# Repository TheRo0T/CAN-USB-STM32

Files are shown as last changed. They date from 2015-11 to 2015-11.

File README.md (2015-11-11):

# CAN-USB-STM32
CAN-USB adapter based on [STM32F105](http://www.st.com/web/en/catalog/mmc/SC1169/SS1031/LN1564) microprocessor

Fault tolerant [CAN](https://en.wikipedia.org/wiki/CAN) using [TJA1055T](http://www.nxp.com/products/interface_and_connectivity/can_lin_flexray_transceivers/can_transceivers/TJA1055T.html)

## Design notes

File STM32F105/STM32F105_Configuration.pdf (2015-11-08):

## STM32F105 Project Configuration Report

# 1. Description

## 1.1. Project

Project Name | STM32F105
Board Name | STM32F105
Generated with: | STM32CubeMX 4.11.0
Date | 11/07/2015

## 1.2. MCU

MCU Series | STM32F1
MCU Line | STM32F105/107
MCU name | STM32F105RBTx
MCU Package | LQFP64
MCU Pin number | 64

# 2. Pinout Configuration

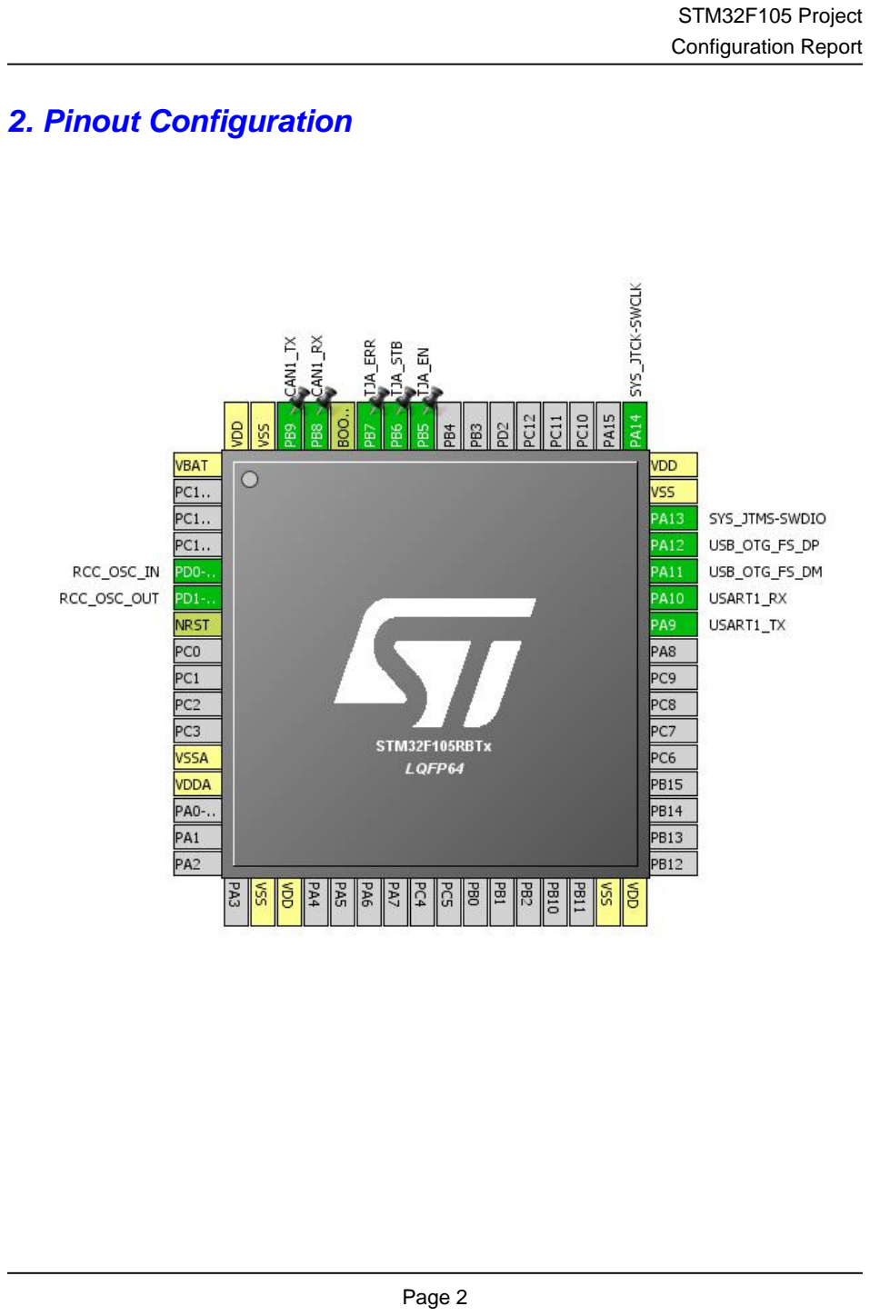
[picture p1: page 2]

# 3. Pins Configuration

Pin Number LQFP64 | Pin Name (function after reset) | Pin Type | Alternate Function(s) | Label
1 | VBAT | Power
5 | PD0-OSC_IN | I/O | RCC_OSC_IN
6 | PD1-OSC_OUT | I/O | RCC_OSC_OUT
7 | NRST | Reset
12 | VSSA | Power
13 | VDDA | Power
18 | VSS | Power
19 | VDD | Power
31 | VSS | Power
32 | VDD | Power
42 | PA9 | I/O | USART1_TX
43 | PA10 | I/O | USART1_RX
44 | PA11 | I/O | USB_OTG_FS_DM
45 | PA12 | I/O | USB_OTG_FS_DP
46 | PA13 | I/O | SYS_JTMS-SWDIO
47 | VSS | Power
48 | VDD | Power
49 | PA14 | I/O | SYS_JTCK-SWCLK
57 | PB5 * | I/O | GPIO_Output | TJA_EN
58 | PB6 * | I/O | GPIO_Output | TJA_STB
59 | PB7 * | I/O | GPIO_Input | TJA_ERR
60 | BOOT0 | Boot
61 | PB8 | I/O | CAN1_RX
62 | PB9 | I/O | CAN1_TX
63 | VSS | Power
64 | VDD | Power

## * The pin is affected with an I/O function

# 4. Clock Tree Configuration

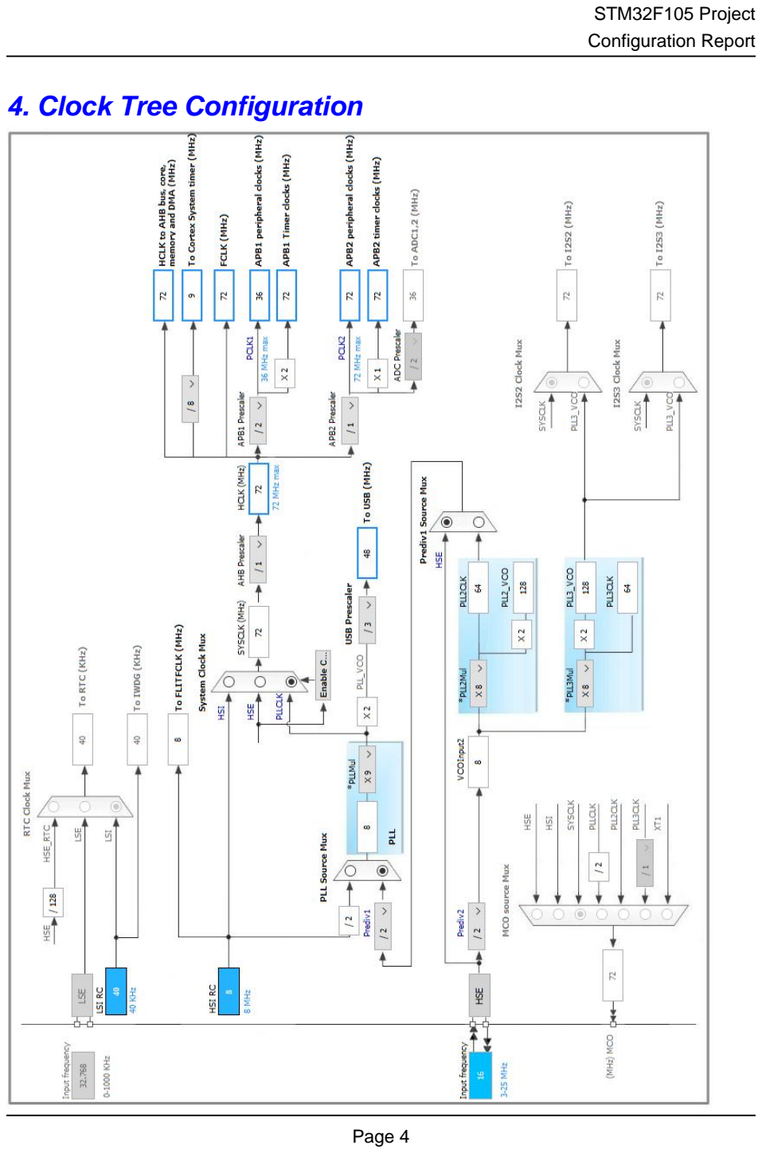
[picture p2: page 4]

# 5. IPs and Middleware Configuration

# 5.1. CAN1

## mode: Mode

## 5.1.1. Parameter Settings:

### Bit Timings Parameters:

Prescaler (for Time Quantum) | 6 *
Time Quantum | 166.66666666666669 *
Time Quanta in Bit Segment 1 | 6 Times *
Time Quanta in Bit Segment 2 | 5 Times *
Time for one Bit | 2000 *
ReSynchronization Jump Width | 1 Time

### Basic Parameters:

Time Triggered Communication Mode | Disable
Automatic Bus-Off Management | Disable
Automatic Wake-Up Mode | Disable
No-Automatic Retransmission | Disable
Receive Fifo Locked Mode | Disable
Transmit Fifo Priority | Disable

### Advanced Parameters:

Operating Mode | Loopback combined with Silent *

# 5.2. RCC

## High Speed Clock (HSE): Crystal/Ceramic Resonator

## 5.2.1. Parameter Settings:

### System Parameters:

VDD voltage (V) | 3.3
Instruction Cache | Enabled
Prefetch Buffer | Enabled
Data Cache | Enabled
Flash Latency(WS) | 2 WS (3 CPU cycle)

### RCC Parameters:

HSI Calibration Value | 16

# 5.3. SYS

## Debug: Serial-Wire

# 5.4. USART1

## Mode: Asynchronous

## 5.4.1. Parameter Settings:

### Basic Parameters:

Baud Rate | 115200
Word Length | 8 Bits (including Parity)
Parity | None
Stop Bits | 1

### Advanced Parameters:

Data Direction | Receive and Transmit
Over Sampling | 16 Samples

# 5.5. USB_OTG_FS

## Mode: Device_Only

## 5.5.1. Parameter Settings:

Speed | Device Full Speed 12MBit/s
Endpoint 0 Max Packet size | 64 Bytes
Low power | Disabled
VBUS sensing | Disabled

# 5.6. FREERTOS

## mode: Enabled

## 5.6.1. Config parameters:

### Versions:

CMSIS-RTOS version | 1.02
FreeRTOS version | 8.2.1

### Kernel settings:

USE_PREEMPTION | Enabled
CPU_CLOCK_HZ | SystemCoreClock
TICK_RATE_HZ | 1000
MAX_PRIORITIES | 7
MINIMAL_STACK_SIZE | 128
MAX_TASK_NAME_LEN | 16
USE_16_BIT_TICKS | Disabled
IDLE_SHOULD_YIELD | Enabled
USE_MUTEXES | Enabled
USE_RECURSIVE_MUTEXES | Enabled
USE_COUNTING_SEMAPHORES | Enabled
QUEUE_REGISTRY_SIZE | 8
USE_APPLICATION_TASK_TAG | Disabled
TOTAL_HEAP_SIZE | 4096
Memory Management scheme | heap_4
USE_ALTERNATIVE_API | Disabled
ENABLE_BACKWARD_COMPATIBILITY | Enabled
USE_PORT_OPTIMISED_TASK_SELECTION | Disabled
USE_TICKLESS_IDLE | Disabled

### Hook function related definitions:

USE_IDLE_HOOK | Disabled
USE_TICK_HOOK | Disabled
USE_MALLOC_FAILED_HOOK | Disabled
CHECK_FOR_STACK_OVERFLOW | Disabled

### Run time and task stats gathering related definitions:

USE_TRACE_FACILITY | Enabled
GENERATE_RUN_TIME_STATS | Disabled

### Co-routine related definitions:

USE_CO_ROUTINES | Disabled
MAX_CO_ROUTINE_PRIORITIES | 2

### Software timer definitions:

USE_TIMERS | Disabled
TIMER_TASK_PRIORITY | 2
TIMER_QUEUE_LENGTH | 10

### Interrupt nesting behaviour configuration:

LIBRARY_LOWEST_INTERRUPT_PRIORITY | 15
LIBRARY_MAX_SYSCALL_INTERRUPT_PRIORITY | 5

## 5.6.2. Include parameters:

### Include definitions:

vTaskPrioritySet | Enabled
uxTaskPriorityGet | Enabled
vTaskDelete | Enabled
vTaskCleanUpResources | Disabled
vTaskSuspend | Enabled
vTaskDelayUntil | Disabled
vTaskDelay | Enabled
xTaskGetSchedulerState | Enabled
xTaskResumeFromISR | Enabled
xQueueGetMutexHolder | Disabled
xSemaphoreGetMutexHolder | Disabled
pcTaskGetTaskName | Disabled
uxTaskGetStackHighWaterMark | Disabled
xTaskGetCurrentTaskHandle | Disabled
eTaskGetState | Disabled
xEventGroupSetBitFromISR | Disabled
xTimerPendFunctionCall | Disabled

# 5.7. USB_DEVICE

## Class For FS IP: Communication Device Class (Virtual Port Com)

## 5.7.1. Parameter Settings:

### Basic Parameters:

USBD_MAX_NUM_INTERFACES (Maximum number of supported interfaces) | 1
USBD_MAX_NUM_CONFIGURATION (Maximum number of supported configuration) | 1
USBD_MAX_STR_DESC_SIZ (Maximum size for the string descriptors) | 512
USBD_SUPPORT_USER_STRING (Enable user string descriptor) | Disabled
USBD_SELF_POWERED (Enabled self power) | Enabled
USBD_DEBUG_LEVEL (USBD Debug Level) | 0: No debug message

### Class Parameters:

USBD_CDC_INTERVAL (Number of micro-frames interval) | 1000

## 5.7.2. Device Descriptor:

### Device Descriptor:

VID (Vendor IDentifier) | 1155
LANGID_STRING (Language Identifier) | English(United States)
MANUFACTURER_STRING (Manufacturer Identifier) | STMicroelectronics

### Device Descriptor FS:

PID (Product IDentifier) | 22336
PRODUCT_STRING (Product Identifier) | STM32 Virtual ComPort
SERIALNUMBER_STRING (Serial number) | 00000000001A
CONFIGURATION_STRING (Configuration Identifier) | CDC Config
INTERFACE_STRING (Interface Identifier) | CDC Interface

### * User modified value

# 6. System Configuration

# 6.1. GPIO configuration

IP | Pin | Signal | GPIO mode | GPIO pull/up pull down | Max Speed | User Label
CAN1 | PB8 | CAN1_RX | Input mode | No pull-up and no pull-down | n/a
| PB9 | CAN1_TX | Alternate Function Push Pull | n/a | High *
RCC | PD0-OSC_IN | RCC_OSC_IN | n/a | n/a | n/a
| PD1-OSC_OUT | RCC_OSC_OUT | n/a | n/a | n/a
SYS | PA13 | SYS_JTMS-SWDIO | n/a | n/a | n/a
| PA14 | SYS_JTCK-SWCLK | n/a | n/a | n/a
USART1 | PA9 | USART1_TX | Alternate Function Push Pull | n/a | High *
| PA10 | USART1_RX | Input mode | No pull-up and no pull-down | n/a
USB_OTG_ FS | PA11 | USB_OTG_FS_ DM | n/a | n/a | n/a
| PA12 | USB_OTG_FS_ DP | n/a | n/a | n/a
GPIO | PB5 | GPIO_Output | Output Push Pull | n/a | Low | TJA_EN
| PB6 | GPIO_Output | Output Push Pull | n/a | Low | TJA_STB
| PB7 | GPIO_Input | Input mode | No pull-up and no pull-down | n/a | TJA_ERR

# 6.2. DMA configuration

DMA request | Stream | Direction | Priority
USART1_TX | DMA1_Channel4 | Memory To Peripheral | Low
USART1_RX | DMA1_Channel5 | Peripheral To Memory | Low

## USART1_TX: DMA1_Channel4 DMA request Settings:

Mode: | Normal
Peripheral Increment: | Disable
Memory Increment: | Enable *
Peripheral Data Width: | Byte
Memory Data Width: | Byte

## USART1_RX: DMA1_Channel5 DMA request Settings:

Mode: | Circular *
Peripheral Increment: | Disable
Memory Increment: | Enable *
Peripheral Data Width: | Byte
Memory Data Width: | Byte

# 6.3. NVIC configuration

Interrupt Table | Enable | Preenmption Priority | SubPriority
System tick timer | true | 0 | 0
DMA1 channel4 global interrupt | true | 5 | 0
DMA1 channel5 global interrupt | true | 5 | 0
CAN1 TX interrupt | true | 5 | 0
CAN1 RX0 interrupt | true | 5 | 0
CAN1 RX1 interrupt | true | 5 | 0
CAN1 SCE interrupt | true | 5 | 0
USART1 global interrupt | true | 5 | 0
USB OTG FS global interrupt | true | 5 | 0
Non maskable interrupt | unused
Memory management fault | unused
Prefetch fault, memory access fault | unused
Undefined instruction or illegal state | unused
Debug monitor | unused
PVD interrupt through EXTI line 16 | unused
Flash global interrupt | unused
RCC global interrupt | unused

### * User modified value

# 7. Power Plugin report

## 7.1. Microcontroller Selection

Series | STM32F1
Line | STM32F105/107
MCU | STM32F105RBTx
Datasheet | 15274_Rev9

## 7.2. Parameter Selection

Temperature | 25
Vdd | 3.3

# 8. Software Project

## 8.1. Project Settings

Name | Value
Project Name | STM32F105
Project Folder | C:\Users\Dmitry\workspace\STM32F105\STM32F105
Toolchain / IDE | SW4STM32
Firmware Package Name and Version | STM32Cube FW_F1 V1.2.0

## 8.2. Code Generation Settings

Name | Value
STM32Cube Firmware Library Package | Copy all used libraries into the project folder
Generate peripheral initialization as a pair of '.c/.h' files | No
Backup previously generated files when re-generating | No
Delete previously generated files when not re-generated | Yes
Set all free pins as analog (to optimize the power consumption) | No

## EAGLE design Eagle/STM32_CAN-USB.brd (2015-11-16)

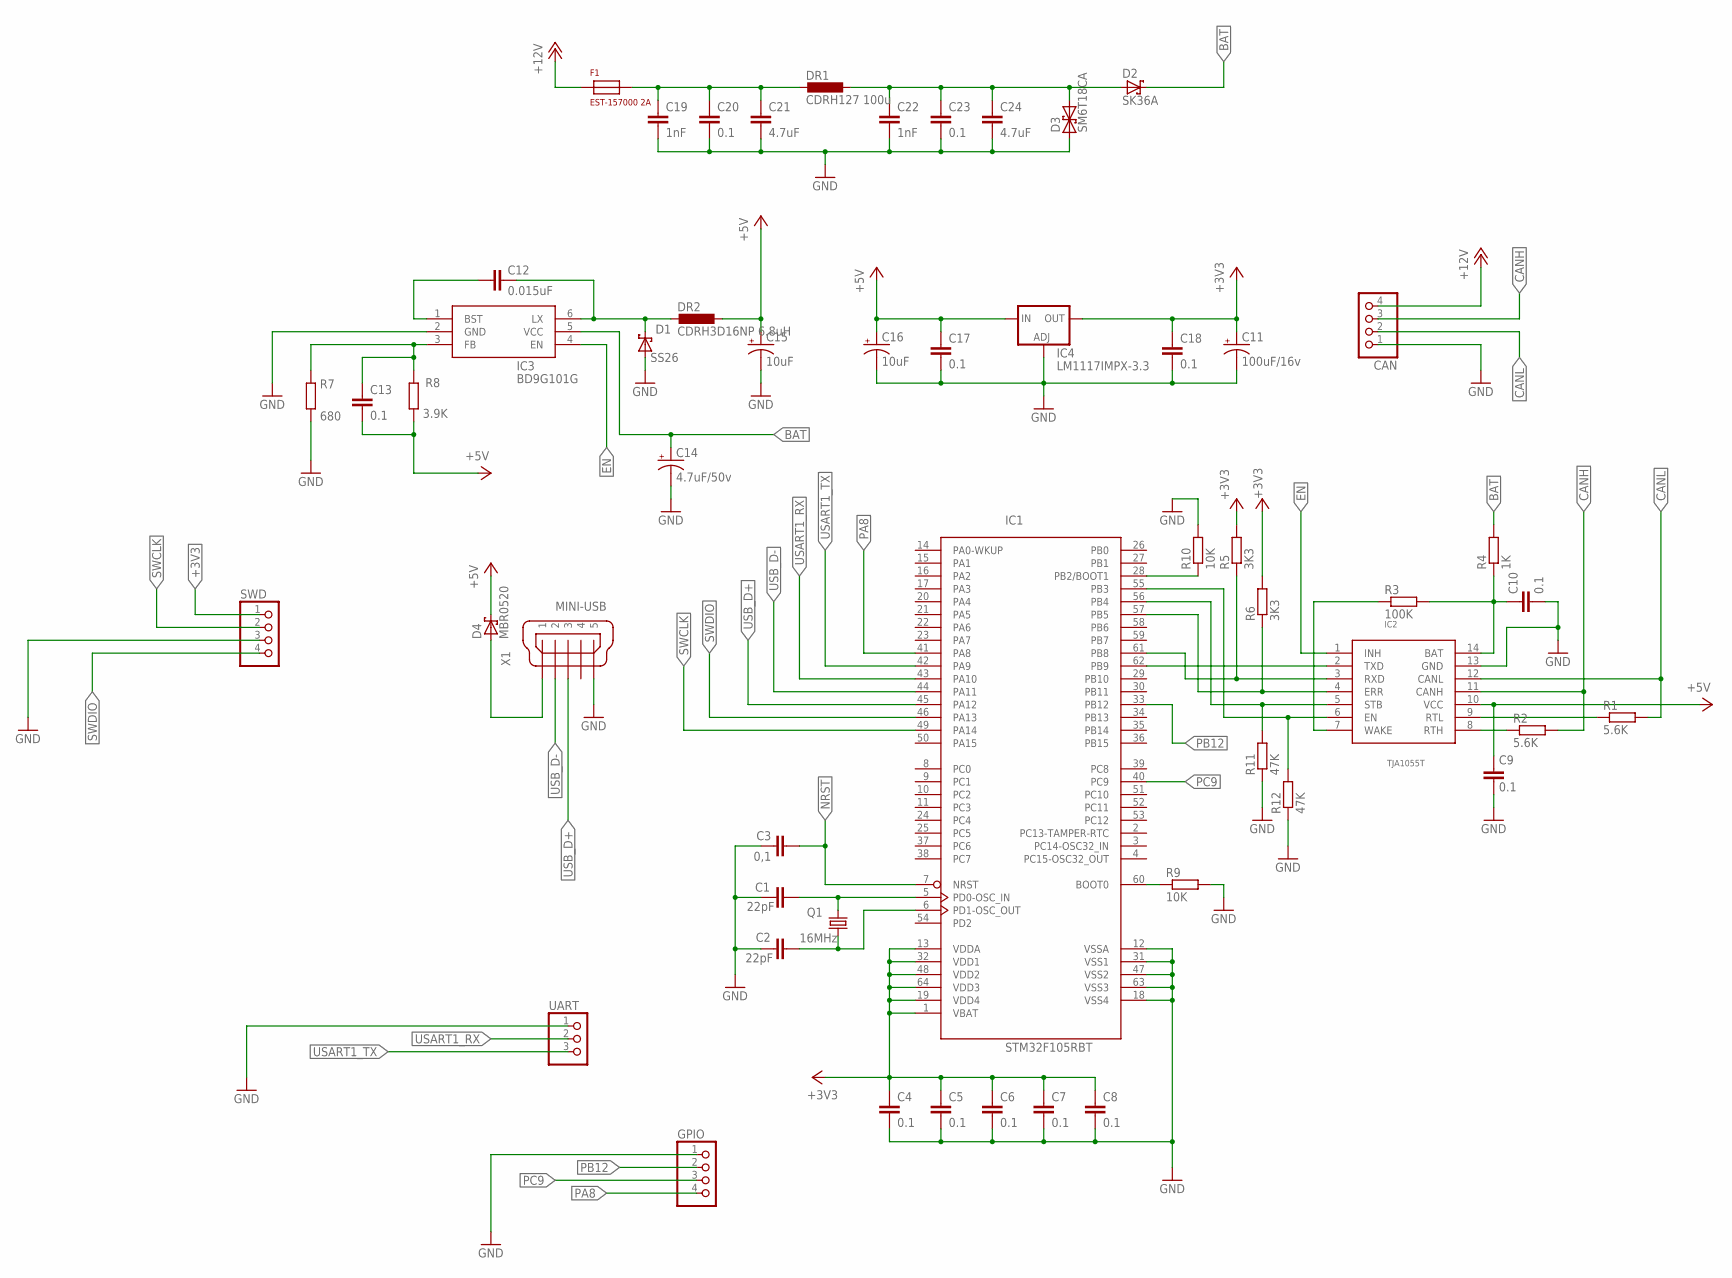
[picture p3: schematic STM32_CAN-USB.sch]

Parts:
C1, C2: 22pF; C0805
C3: 0,1; C0805
C4, C5, C6, C7, C8, C9, C10, C13, C17, C18, C20, C23: 0.1; C0805
C11: 100uF/16v; 153CLV-0605
C12: 0.015uF; C0805
C14: 4.7uF/50v; 153CLV-0605
C15, C16: 10uF; 153CLV-0605
C19, C22: 1nF; C0805
C21, C24: 4.7uF; C0805
CAN: PINHD-1X4; 1X04
D1: SS26; SMB
D2: SK36A; DO-214AC
D3: SM6T18CA; DO214AA
D4: MBR0520; SOD123
DR1: CDRH127 100u; MS85
DR2: CDRH3D16NP 6.8uH; CDRH3D16NP
F1: EST-157000 2A; FUSE
GPIO: PINHD-1X4; 1X04
IC1: STM32F105RBT; LQFP64
IC2: TJA1055T; SO-14W
IC3: BD9G101G; SSOP6
IC4: LM1117IMPX-3.3; SOT223
Q1: 16MHz; HC49UP
R1, R2: 5.6K; R0805
R3: 100K; R0805
R4: 1K; R0805
R5, R6: 3K3; R0805
R7: 680; R0805
R8: 3.9K; R0805
R9, R10: 10K; R0805
R11, R12: 47K; R0805
SWD: PINHD-1X4; 1X04
UART: PINHD-1X3; 1X03
X1: MINI-USB; UX60-MB-5ST

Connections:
+3V3: C4.1, C5.1, C6.1, C7.1, C8.1, C11.+, C18.1, IC1.1 (VBAT), IC1.13 (VDDA), IC1.19 (VDD4), IC1.32 (VDD1), IC1.48 (VDD2), IC1.64 (VDD3), IC4.2 (OUT), IC4.4 (OUT), R5.2, R6.2, SWD.1
+5V: C9.1, C13.2, C15.+, C16.+, C17.1, D4.C, DR2.P$2 (2), IC2.10 (VCC), IC4.3 (IN), R8.1
+12V: CAN.4, F1.P$1 (1)
BAT: C14.+, D2.C, IC3.5 (VCC), R4.2
CANH: CAN.3, IC2.11 (CANH), R2.2
CANL: CAN.2, IC2.12 (CANL), R1.2
EN: IC2.1 (INH), IC3.4 (EN)
GND: C1.2, C2.2, C3.1, C4.2, C5.2, C6.2, C7.2, C8.2, C9.2, C10.2, C11.-, C14.-, C15.-, C16.-, C17.2, C18.2, C19.2, C20.2, C21.2, C22.2, C23.2, C24.2, CAN.1, D1.A, D3.A (1), GPIO.1, IC1.12 (VSSA), IC1.18 (VSS4), IC1.31 (VSS1), IC1.47 (VSS2), IC1.63 (VSS3), IC2.13 (GND), IC3.2 (GND), IC4.1 (ADJ), R7.1, R9.2, R10.2, R11.1, R12.1, SWD.3, UART.1, X1.5, X1.M1 (5), X1.M2 (5)
unnamed: C1.1, IC1.5 (PD0-OSC_IN), Q1.2
unnamed: C2.1, IC1.6 (PD1-OSC_OUT), Q1.1
unnamed: IC1.60 (BOOT0), R9.1
unnamed: IC1.61 (PB8), IC2.3 (RXD), R5.1
unnamed: IC1.62 (PB9), IC2.2 (TXD)
unnamed: IC1.56 (PB4), IC2.5 (STB), R11.2
unnamed: IC2.8 (RTH), R2.1
unnamed: IC2.9 (RTL), R1.1
unnamed: C12.1, IC3.1 (BST)
unnamed: IC2.7 (WAKE), R3.1
unnamed: C10.1, IC2.14 (BAT), R3.2, R4.1
unnamed: C12.2, D1.C, DR2.P$1 (1), IC3.6 (LX)
unnamed: C13.1, IC3.3 (FB), R7.2, R8.2
unnamed: IC1.55 (PB3), IC2.6 (EN), R12.2
unnamed: IC1.57 (PB5), IC2.4 (ERR), R6.1
unnamed: IC1.28 (PB2/BOOT1), R10.1
unnamed: C22.1, C23.1, C24.1, D2.A, D3.C (2), DR1.P$2 (2)
unnamed: C19.1, C20.1, C21.1, DR1.P$1 (1), F1.P$2 (2)
unnamed: D4.A, X1.1
NRST: C3.2, IC1.7 (NRST)
PA8: GPIO.4, IC1.41 (PA8)
PB12: GPIO.2, IC1.33 (PB12)
PC9: GPIO.3, IC1.40 (PC9)
SWCLK: IC1.49 (PA14), SWD.2
SWDIO: IC1.46 (PA13), SWD.4
USART1_RX: IC1.43 (PA10), UART.2
USART1_TX: IC1.42 (PA9), UART.3
USB_D+: IC1.45 (PA12), X1.3
USB_D-: IC1.44 (PA11), X1.2

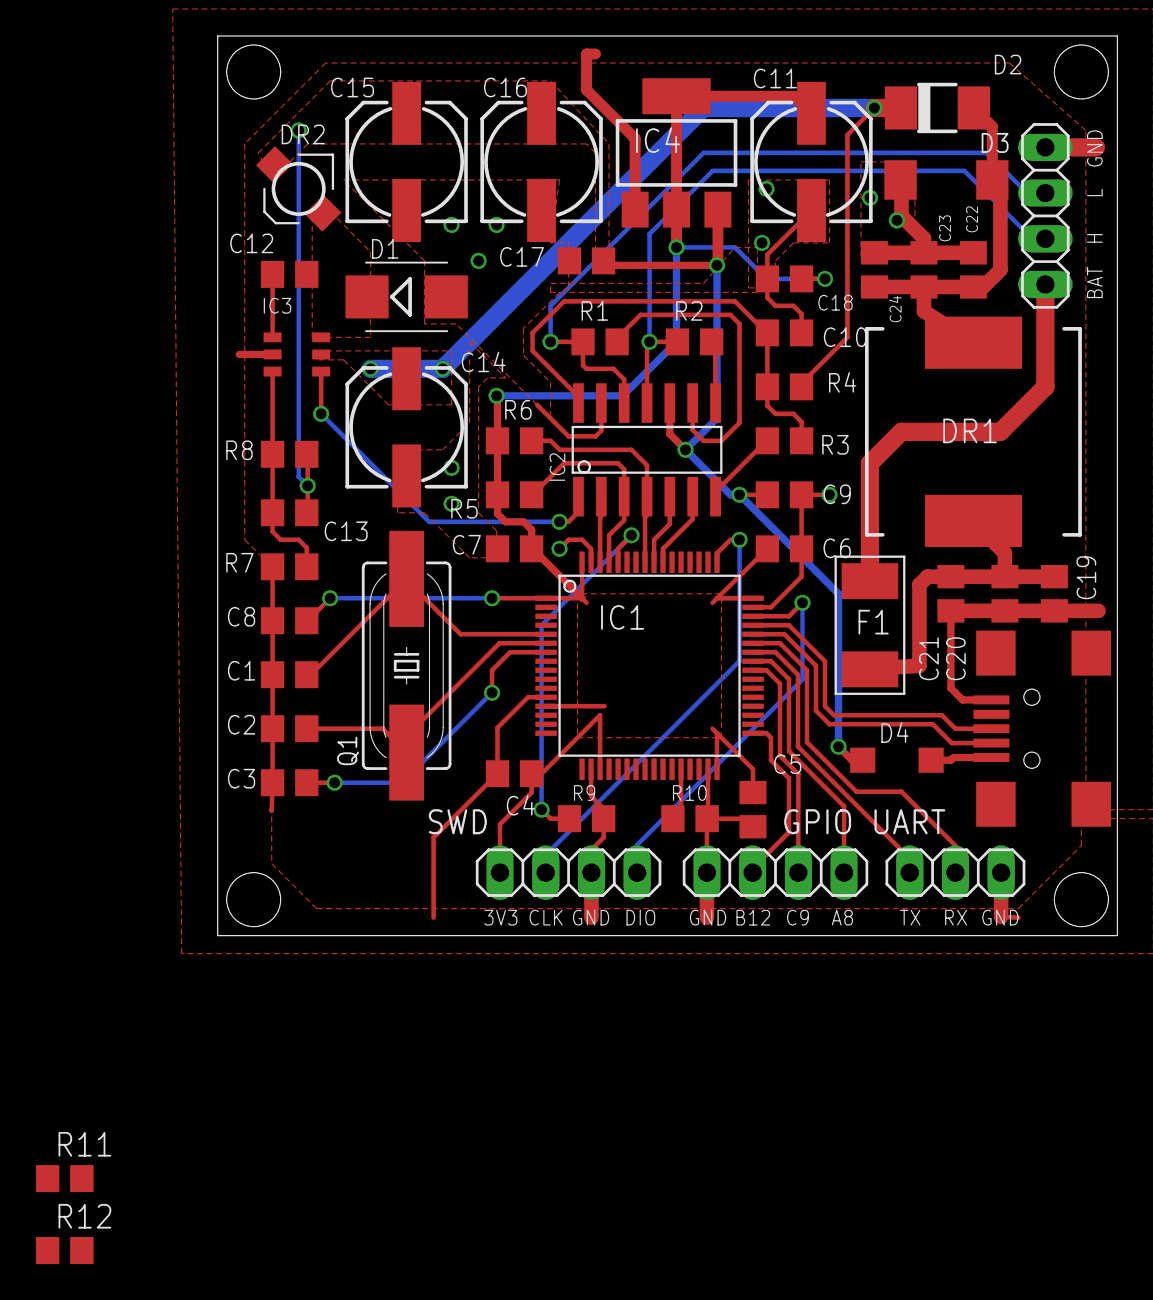
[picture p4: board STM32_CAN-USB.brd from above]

Board: 2 copper layers, 50.0 x 50.0 mm, 53 parts (0 on the bottom side), 37 nets.

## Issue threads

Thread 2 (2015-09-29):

Отверстия по углам слишком близко

autowp, 2015-09-29:
Отодвинуть от отверстий pin-header'ы, мешающие винтам

autowp, 2015-11-12:
Fixed https://github.com/TheRo0T/CAN-USB-STM32/commit/9308639844096602d4c6fb7fe465f3dd1f850d11

Closed 2015-11-12.

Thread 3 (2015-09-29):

Маркировка контактов

autowp, 2015-09-29:
Нанести слой с названиями контактов
- [x] SWD
- [x] UART
- [x] CAN
- [x] GPIO

autowp, 2015-11-05:
https://github.com/TheRo0T/CAN-USB-STM32/commit/35073f4e0025a2ff9baa2b1c0c24b0d2092b634e

autowp, 2015-11-11:
CAN - https://github.com/TheRo0T/CAN-USB-STM32/commit/147e032a0dbb3c5a9067781c5d7b40ddfc98dc47

autowp, 2015-11-12:
GPIO UART https://github.com/TheRo0T/CAN-USB-STM32/commit/9308639844096602d4c6fb7fe465f3dd1f850d11

Closed 2015-11-12.

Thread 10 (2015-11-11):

HAL CAN lock issue

autowp, 2015-11-11:
Решить проблему с падением CAN в Busy
[ST forum](https://my.st.com/public/STe2ecommunities/mcu/Lists/STM32Java/Flat.aspx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)

autowp, 2015-11-20:
Attempt to fix https://github.com/TheRo0T/CAN-USB-STM32/commit/cdca315223ea597243ea4956ae588b31252e0dda

Closed 2015-11-20.

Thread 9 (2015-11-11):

PWR LED

autowp, 2015-11-11:
Добавить индикацию наличия +5V (после DC-DC)
С учётом цели на корпус: не-smd.
Как вариант: 2-pin сокет для подключения светодиода на проводке, для отвязки от расположения на плате.

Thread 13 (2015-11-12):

RST button

autowp, 2015-11-12:
Добавить кнопку сброса

autowp, 2015-11-12:
Предлагаю объединить в 4-pin female (2x2) header кнопку сброса и светодиод PWR LED https://github.com/TheRo0T/CAN-USB-STM32/issues/9

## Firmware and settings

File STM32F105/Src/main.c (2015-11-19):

/**
  ******************************************************************************
  * File Name          : main.c
  * Description        : Main program body
  ******************************************************************************
  *
  * COPYRIGHT(c) 2015 STMicroelectronics
  *
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
  ******************************************************************************
  */
/* Includes ------------------------------------------------------------------*/
#include "stm32f1xx_hal.h"
#include "cmsis_os.h"
#include "usb_device.h"

/* USER CODE BEGIN Includes */
#include <string.h>
#include <stdlib.h>
#include "canhacker.h"
#include "tja1055.h"
/* USER CODE END Includes */

CAN_HandleTypeDef hcan1;

TIM_HandleTypeDef htim6;

UART_HandleTypeDef huart1;
DMA_HandleTypeDef hdma_usart1_tx;
DMA_HandleTypeDef hdma_usart1_rx;

osThreadId defaultTaskHandle;
osThreadId uartRxDmaTaskHandle;
osMessageQId uartTxQueueHandle;
osMessageQId canRxQueueHandle;
osMessageQId canTxQueueHandle;

/* USER CODE BEGIN PV */
#define UART_RX_LINE_BUFFER 80
int timer = 0;
uint8_t uartLine[UART_RX_LINE_BUFFER];
int uartLineIndex = 0;
#define UART_RX_BUFFER 256

CAN_HandleTypeDef hcan1;
static CanTxMsgTypeDef        can1TxMessage;
static CanRxMsgTypeDef        can1RxMessage;

TJA1055_HandleTypeDef tja1055;
CanHacker_HandleTypeDef hcanhacker;

typedef struct
{
    uint8_t buffer[UART_RX_BUFFER];
    uint8_t readed;
    uint8_t filled;
    int offset;
} UART_DMA_RX_Buffer;

#define UART_RX_BUFFERS_COUNT 2

UART_DMA_RX_Buffer uartRxBuffer[UART_RX_BUFFERS_COUNT]= {
    { .readed = 1, .filled = 0, .offset = 0 },
    { .readed = 1, .filled = 0, .offset = 0 }
};
int currentUartRxBuffer = 0;
int currentUartRxBufferToRead = 0;

/* USER CODE END PV */

void SystemClock_Config(void);
static void MX_GPIO_Init(void);
static void MX_DMA_Init(void);
static void MX_CAN1_Init(void);
static void MX_TIM6_Init(void);
static void MX_USART1_UART_Init(void);
void StartDefaultTask(void const * argument);
void StartUartRxDmaTask(void const * argument);

/* USER CODE BEGIN PFP */
void throwError(char *msg);

void txUart();
void txCan();
void rxCan();
void transmitErrorMessage(char *message);
/* USER CODE END PFP */

int main(void)
{

  /* MCU Configuration----------------------------------------------------------*/

  /* Reset of all peripherals, Initializes the Flash interface and the Systick. */
  HAL_Init();

  /* Configure the system clock */
  SystemClock_Config();

  /* Initialize all configured peripherals */
  MX_GPIO_Init();
  MX_DMA_Init();
  MX_CAN1_Init();
  MX_TIM6_Init();
  MX_USART1_UART_Init();

  /* USER CODE BEGIN 2 */

    tja1055.enPort = GPIOB;
    tja1055.enPin = TJA_EN_Pin;
    tja1055.errPort = GPIOB;
    tja1055.errPin = TJA_ERR_Pin;
    tja1055.stbPort = GPIOB;
    tja1055.stbPin = TJA_STB_Pin;
    TJA1055_Init(&tja1055);

    CanHacker_Init(&hcanhacker);

    hcan1.pTxMsg = &can1TxMessage;
    hcan1.pRxMsg = &can1RxMessage;


    CAN_FilterConfTypeDef canFilterConfig;
    canFilterConfig.FilterNumber = 0;
    canFilterConfig.FilterMode = CAN_FILTERMODE_IDMASK;
    canFilterConfig.FilterScale = CAN_FILTERSCALE_32BIT;
    canFilterConfig.FilterIdHigh = 0x0000;
    canFilterConfig.FilterIdLow = 0x0000;
    canFilterConfig.FilterMaskIdHigh = 0x0000 << 5;
    canFilterConfig.FilterMaskIdLow = 0x0000;
    canFilterConfig.FilterFIFOAssignment = 0;
    canFilterConfig.FilterActivation = ENABLE;
    canFilterConfig.BankNumber = 1;
    HAL_CAN_ConfigFilter(&hcan1, &canFilterConfig);

  /* USER CODE END 2 */

  /* USER CODE BEGIN RTOS_MUTEX */
  /* add mutexes, ... */
  /* USER CODE END RTOS_MUTEX */

  /* USER CODE BEGIN RTOS_SEMAPHORES */
  /* add semaphores, ... */
  /* USER CODE END RTOS_SEMAPHORES */

  /* USER CODE BEGIN RTOS_TIMERS */
  /* start timers, add new ones, ... */
  /* USER CODE END RTOS_TIMERS */

  /* Create the thread(s) */
  /* definition and creation of defaultTask */
  osThreadDef(defaultTask, StartDefaultTask, osPriorityNormal, 0, 128);
  defaultTaskHandle = osThreadCreate(osThread(defaultTask), NULL);

  /* definition and creation of uartRxDmaTask */
  osThreadDef(uartRxDmaTask, StartUartRxDmaTask, osPriorityIdle, 0, 128);
  uartRxDmaTaskHandle = osThreadCreate(osThread(uartRxDmaTask), NULL);

  /* USER CODE BEGIN RTOS_THREADS */
  /* add threads, ... */
  /* USER CODE END RTOS_THREADS */

  /* Create the queue(s) */
  /* definition and creation of uartTxQueue */
  osMessageQDef(uartTxQueue, 16, int);
  uartTxQueueHandle = osMessageCreate(osMessageQ(uartTxQueue), NULL);

  /* definition and creation of canRxQueue */
  osMessageQDef(canRxQueue, 16, int);
  canRxQueueHandle = osMessageCreate(osMessageQ(canRxQueue), NULL);

  /* definition and creation of canTxQueue */
  osMessageQDef(canTxQueue, 16, int);
  canTxQueueHandle = osMessageCreate(osMessageQ(canTxQueue), NULL);

  /* USER CODE BEGIN RTOS_QUEUES */
  /* add queues, ... */
  /* USER CODE END RTOS_QUEUES */
 

  /* Start scheduler */
  osKernelStart();
  
  /* We should never get here as control is now taken by the scheduler */

  /* Infinite loop */
  /* USER CODE BEGIN WHILE */
  while (1)
  {

      osDelay(1000);

  /* USER CODE END WHILE */

  /* USER CODE BEGIN 3 */

  }
  /* USER CODE END 3 */

}

/** System Clock Configuration
*/
void SystemClock_Config(void)
{

  RCC_OscInitTypeDef RCC_OscInitStruct;
  RCC_ClkInitTypeDef RCC_ClkInitStruct;
  RCC_PeriphCLKInitTypeDef PeriphClkInit;

  RCC_OscInitStruct.OscillatorType = RCC_OSCILLATORTYPE_HSE;
  RCC_OscInitStruct.HSEState = RCC_HSE_ON;
  RCC_OscInitStruct.HSEPredivValue = RCC_HSE_PREDIV_DIV2;
  RCC_OscInitStruct.Prediv1Source = RCC_PREDIV1_SOURCE_HSE;
  RCC_OscInitStruct.PLL.PLLState = RCC_PLL_ON;
  RCC_OscInitStruct.PLL.PLLSource = RCC_PLLSOURCE_HSE;
  RCC_OscInitStruct.PLL.PLLMUL = RCC_PLL_MUL9;
  RCC_OscInitStruct.PLL2.PLL2State = RCC_PLL_NONE;
  HAL_RCC_OscConfig(&RCC_OscInitStruct);

  RCC_ClkInitStruct.ClockType = RCC_CLOCKTYPE_SYSCLK|RCC_CLOCKTYPE_PCLK1;
  RCC_ClkInitStruct.SYSCLKSource = RCC_SYSCLKSOURCE_PLLCLK;
  RCC_ClkInitStruct.AHBCLKDivider = RCC_SYSCLK_DIV1;
  RCC_ClkInitStruct.APB1CLKDivider = RCC_HCLK_DIV4;
  RCC_ClkInitStruct.APB2CLKDivider = RCC_HCLK_DIV1;
  HAL_RCC_ClockConfig(&RCC_ClkInitStruct, FLASH_LATENCY_2);

  PeriphClkInit.PeriphClockSelection = RCC_PERIPHCLK_USB;
  PeriphClkInit.UsbClockSelection = RCC_USBPLLCLK_DIV3;
  HAL_RCCEx_PeriphCLKConfig(&PeriphClkInit);

  HAL_SYSTICK_Config(HAL_RCC_GetHCLKFreq()/8000);

  HAL_SYSTICK_CLKSourceConfig(SYSTICK_CLKSOURCE_HCLK_DIV8);

  __HAL_RCC_PLLI2S_ENABLE();

  /* SysTick_IRQn interrupt configuration */
  HAL_NVIC_SetPriority(SysTick_IRQn, 0, 0);
}

/* CAN1 init function */
void MX_CAN1_Init(void)
{

  hcan1.Instance = CAN1;
  hcan1.Init.Prescaler = 6;
  hcan1.Init.Mode = CAN_MODE_SILENT_LOOPBACK;
  hcan1.Init.SJW = CAN_SJW_1TQ;
  hcan1.Init.BS1 = CAN_BS1_6TQ;
  hcan1.Init.BS2 = CAN_BS2_5TQ;
  hcan1.Init.TTCM = DISABLE;
  hcan1.Init.ABOM = DISABLE;
  hcan1.Init.AWUM = DISABLE;
  hcan1.Init.NART = DISABLE;
  hcan1.Init.RFLM = DISABLE;
  hcan1.Init.TXFP = DISABLE;
  HAL_CAN_Init(&hcan1);

}

/* TIM6 init function */
void MX_TIM6_Init(void)
{

  TIM_MasterConfigTypeDef sMasterConfig;

  htim6.Instance = TIM6;
  htim6.Init.Prescaler = 35999;
  htim6.Init.CounterMode = TIM_COUNTERMODE_UP;
  htim6.Init.Period = 60000;
  HAL_TIM_Base_Init(&htim6);

  sMasterConfig.MasterOutputTrigger = TIM_TRGO_RESET;
  sMasterConfig.MasterSlaveMode = TIM_MASTERSLAVEMODE_DISABLE;
  HAL_TIMEx_MasterConfigSynchronization(&htim6, &sMasterConfig);

}

/* USART1 init function */
void MX_USART1_UART_Init(void)
{

  huart1.Instance = USART1;
  huart1.Init.BaudRate = 115200;
  huart1.Init.WordLength = UART_WORDLENGTH_8B;
  huart1.Init.StopBits = UART_STOPBITS_1;
  huart1.Init.Parity = UART_PARITY_NONE;
  huart1.Init.Mode = UART_MODE_TX_RX;
  huart1.Init.HwFlowCtl = UART_HWCONTROL_NONE;
  huart1.Init.OverSampling = UART_OVERSAMPLING_16;
  HAL_UART_Init(&huart1);

}

/** 
  * Enable DMA controller clock
  */
void MX_DMA_Init(void) 
{
  /* DMA controller clock enable */
  __HAL_RCC_DMA1_CLK_ENABLE();

  /* DMA interrupt init */
  HAL_NVIC_SetPriority(DMA1_Channel4_IRQn, 5, 0);
  HAL_NVIC_EnableIRQ(DMA1_Channel4_IRQn);
  HAL_NVIC_SetPriority(DMA1_Channel5_IRQn, 5, 0);
  HAL_NVIC_EnableIRQ(DMA1_Channel5_IRQn);

}

/** Configure pins as 
        * Analog 
        * Input 
        * Output
        * EVENT_OUT
        * EXTI
*/
void MX_GPIO_Init(void)
{

  GPIO_InitTypeDef GPIO_InitStruct;

  /* GPIO Ports Clock Enable */
  __HAL_RCC_GPIOD_CLK_ENABLE();
  __HAL_RCC_GPIOA_CLK_ENABLE();
  __HAL_RCC_GPIOB_CLK_ENABLE();

  /*Configure GPIO pins : TJA_EN_Pin TJA_STB_Pin */
  GPIO_InitStruct.Pin = TJA_EN_Pin|TJA_STB_Pin;
  GPIO_InitStruct.Mode = GPIO_MODE_OUTPUT_PP;
  GPIO_InitStruct.Speed = GPIO_SPEED_LOW;
  HAL_GPIO_Init(GPIOB, &GPIO_InitStruct);

  /*Configure GPIO pin : TJA_ERR_Pin */
  GPIO_InitStruct.Pin = TJA_ERR_Pin;
  GPIO_InitStruct.Mode = GPIO_MODE_INPUT;
  GPIO_InitStruct.Pull = GPIO_NOPULL;
  HAL_GPIO_Init(TJA_ERR_GPIO_Port, &GPIO_InitStruct);

}

/* USER CODE BEGIN 4 */
/*void MX_CAN1_Init(void)
{

    hcan1.Instance = CAN1;
    hcan1.Init.Prescaler = 6;
    hcan1.Init.Mode = CAN_MODE_SILENT_LOOPBACK;
    hcan1.Init.SJW = CAN_SJW_1TQ;
    hcan1.Init.BS1 = CAN_BS1_6TQ;
    hcan1.Init.BS2 = CAN_BS2_5TQ;
    hcan1.Init.TTCM = DISABLE;
    hcan1.Init.ABOM = DISABLE;
    hcan1.Init.AWUM = DISABLE;
    hcan1.Init.NART = DISABLE;
    hcan1.Init.RFLM = DISABLE;
    hcan1.Init.TXFP = DISABLE;
    HAL_StatusTypeDef canInitResult = HAL_CAN_Init(&hcan1);



    switch (canInitResult) {
        case HAL_OK: break;
        case HAL_ERROR:
            throwError("MX_CAN1_Init: error");
            break;
        case HAL_BUSY:
            throwError("MX_CAN1_Init: busy");
            break;
        case HAL_TIMEOUT:
            throwError("MX_CAN1_Init: timeout");
            break;
    }
}*/

void throwError(char *msg)
{
    transmitErrorMessage(msg);
    while(1) {
        HAL_Delay(1000);
    };
}

void txUart() {
    HAL_UART_StateTypeDef state = HAL_UART_GetState(&huart1);

    if (state == HAL_UART_STATE_BUSY_TX_RX || state == HAL_UART_STATE_BUSY_TX) {
    } else {

        osEvent event = osMessageGet(uartTxQueueHandle, osWaitForever);
        if (event.status == osEventMessage) {
            char *str = event.value.p;
            int len = strlen(str);
            if (len > 0) {
                HAL_StatusTypeDef result = HAL_UART_Transmit_DMA(&huart1, (uint8_t*)str, len);
                switch (result) {
                    case HAL_OK: break;
                    case HAL_ERROR:
                        throwError("HAL_UART_Transmit_IT: error");
                        break;
                    case HAL_BUSY:
                        throwError("HAL_UART_Transmit_IT: busy");
                        break;
                    case HAL_TIMEOUT:
                        throwError("HAL_UART_Transmit_IT: timeout");
                        break;
                }
            } else {
                free(str);
            }
        }
    }
}

void HAL_UART_TxCpltCallback(UART_HandleTypeDef *huart) {
    if (huart->pTxBuffPtr) {
        free(huart->pTxBuffPtr);
    }
    txUart();
}

void startUartDmaReceive(UART_HandleTypeDef *huart, UART_DMA_RX_Buffer *uartRxBuffer) {
    uartRxBuffer->readed = 0;
    HAL_StatusTypeDef result = HAL_UART_Receive_DMA(huart, uartRxBuffer->buffer, UART_RX_BUFFER);
    switch (result) {
        case HAL_OK: break;
        case HAL_ERROR: throwError("HAL_UART_Receive_DMA: error"); break;
        case HAL_BUSY: throwError("HAL_UART_Receive_DMA: busy"); break;
        case HAL_TIMEOUT: throwError("HAL_UART_Receive_DMA: timeout"); break;
    }
}

void HAL_UART_RxCpltCallback(UART_HandleTypeDef *huart) {

    if (huart->Instance == USART1) {
        // switch buffer
        uartRxBuffer[currentUartRxBuffer].filled = 1;
        currentUartRxBuffer++;
        currentUartRxBuffer %= UART_RX_BUFFERS_COUNT;
        if (!uartRxBuffer[currentUartRxBuffer].readed) {
            throwError("UART RX OVERRUN");
        }

        startUartDmaReceive(huart, &uartRxBuffer[currentUartRxBuffer]);
    }
}

void HAL_UART_ErrorCallback(UART_HandleTypeDef *huart) {
    uint32_t code = huart->ErrorCode;
    if (code & HAL_UART_ERROR_PE) { throwError("UART error: Parity error"); }
    if (code & HAL_UART_ERROR_NE) { throwError("UART error: Noise error"); }
    if (code & HAL_UART_ERROR_FE) { throwError("UART error: frame error"); }
    if (code & HAL_UART_ERROR_ORE) { throwError("UART error: Overrun error"); }
    if (code & HAL_UART_ERROR_DMA) { throwError("UART error: DMA error"); }
    char str[80];
    sprintf(str, "Uart error code: %X", (unsigned int)code);
    throwError(str);
}

void HAL_CAN_TxCpltCallback(CAN_HandleTypeDef* hcan) {
    printf("HAL_CAN_TxCpltCallback\n");
    txCan();
}

void HAL_CAN_RxCpltCallback(CAN_HandleTypeDef* hcan) {
    HAL_GPIO_TogglePin(GPIOC, GPIO_PIN_13);
    CanRxMsgTypeDef *rxMsg = malloc(sizeof(CanRxMsgTypeDef));
    memcpy(rxMsg, hcan->pRxMsg, sizeof(CanRxMsgTypeDef));

    osMessagePut (canRxQueueHandle, (uint32_t)rxMsg, osWaitForever);
    rxCan();
}

void HAL_CAN_ErrorCallback(CAN_HandleTypeDef *hcan) {
    throwError("HAL_CAN_ErrorCallback");
}

void rxCan() {
    HAL_StatusTypeDef result = HAL_CAN_Receive_IT(&hcan1, CAN_FIFO0);
    switch (result) {
        case HAL_OK: break;
        case HAL_ERROR:
            throwError("HAL_CAN_Receive_IT: error");
            break;
        case HAL_BUSY:
            throwError("HAL_CAN_Receive_IT: busy");
            break;
        case HAL_TIMEOUT:
            throwError("HAL_CAN_Receive_IT: timeout");
            break;
    }
    switch (hcan1.ErrorCode) {
        case HAL_CAN_ERROR_NONE: break;       /*!< No error             */
        case HAL_CAN_ERROR_EWG:               /*!< EWG error            */
        case HAL_CAN_ERROR_EPV:               /*!< EPV error            */
        case HAL_CAN_ERROR_BOF:               /*!< BOF error            */
        case HAL_CAN_ERROR_STF:               /*!< Stuff error          */
        case HAL_CAN_ERROR_FOR:               /*!< Form error           */
        case HAL_CAN_ERROR_ACK:               /*!< Acknowledgment error */
        case HAL_CAN_ERROR_BR:                /*!< Bit recessive        */
        case HAL_CAN_ERROR_BD:                /*!< LEC dominant         */
        case HAL_CAN_ERROR_CRC:
            throwError("RXCAN ERROR");
            break;
    }
}

void txCan() {
    if (hcan1.State == HAL_CAN_STATE_READY && hcan1.txState == HAL_CAN_RXTX_STATE_READY) {

        osEvent event = osMessageGet(canTxQueueHandle, osWaitForever);
        if (event.status == osEventMessage) {
            //memcpy(hcan.pTxMsg, event.value.p, sizeof(CanTxMsgTypeDef));
            can1TxMessage = *(CanTxMsgTypeDef *)event.value.p;
            HAL_StatusTypeDef result = HAL_CAN_Transmit_IT(&hcan1);
            free(event.value.p);
            switch (result) {
                case HAL_OK: break;
                case HAL_ERROR:
                    throwError("HAL_CAN_Transmit_IT: error");
                    break;
                case HAL_BUSY:
                    throwError("HAL_CAN_Transmit_IT: busy");
                    break;
                case HAL_TIMEOUT:
                    throwError("HAL_CAN_Transmit_IT: timeout");
                    break;
            }
            switch (hcan1.ErrorCode) {
                case HAL_CAN_ERROR_NONE: break;       /*!< No error             */
                case HAL_CAN_ERROR_EWG:               /*!< EWG error            */
                case HAL_CAN_ERROR_EPV:               /*!< EPV error            */
                case HAL_CAN_ERROR_BOF:               /*!< BOF error            */
                case HAL_CAN_ERROR_STF:               /*!< Stuff error          */
                case HAL_CAN_ERROR_FOR:               /*!< Form error           */
                case HAL_CAN_ERROR_ACK:               /*!< Acknowledgment error */
                case HAL_CAN_ERROR_BR:                /*!< Bit recessive        */
                case HAL_CAN_ERROR_BD:                /*!< LEC dominant         */
                case HAL_CAN_ERROR_CRC:
                    throwError("TXCAN error advanced");
                    break;
            }
        }
    } else {
        //printf("State is %d\n", hcan1.State);
        //throwError("State");
    }
}

void transmitErrorMessage(char *message) {
    int len = strlen((char *)message);
    char *str = malloc(len+3);
    memcpy(str, message, len);
    str[len] = '\r';
    str[len+1] = '\n';
    str[len+2] = '\0';


    osMessagePut (uartTxQueueHandle, (uint32_t)str, osWaitForever);
    txUart();

    return;
}

void gotoNextBufferToRead() {
    if (currentUartRxBufferToRead != currentUartRxBuffer) {
        currentUartRxBufferToRead++;
        currentUartRxBufferToRead %= UART_RX_BUFFERS_COUNT;
    }
}

int processUartDmaBuffer(UART_HandleTypeDef *huart, UART_DMA_RX_Buffer *uartRxBuffer) {
    int itemsProcessed = 0;

    if (uartRxBuffer->readed) {
        return itemsProcessed;
    }

    int dmaOffset;
    if (uartRxBuffer->filled) {
        dmaOffset = UART_RX_BUFFER;
    } else {
        dmaOffset = huart->RxXferSize - huart->hdmarx->Instance->CNDTR;
    }
    int bytesReady = dmaOffset - uartRxBuffer->offset;

    if (bytesReady > 0) {

        while(uartRxBuffer->offset < dmaOffset) {
            uint8_t c = uartRxBuffer->buffer[uartRxBuffer->offset];
            switch (c) {
                case '\0':
                case '\r':
                case '\n':
                    if (uartLineIndex > 0) {
                        uartLine[uartLineIndex++] = '\0';
                        /*uint8_t *str = malloc(uartLineIndex);
                        memcpy(str, uartLine, uartLineIndex);*/

                        CanHacker_Receive_Cmd(&hcanhacker, uartLine);

                        uartLineIndex = 0;
                        /*osStatus status = osMessagePut(uartRxQueueHandle, (uint32_t)str, osWaitForever);
                        switch (status) {
                            case osOK:
                                break;
                            default:
                                throwError("Error put to queue");
                                break;
                        }*/
                    }
                    break;
                default:
                    uartLine[uartLineIndex++] = c;
                    break;
            }

            uartRxBuffer->offset++;
        }

        itemsProcessed++;
    }

    if (uartRxBuffer->offset >= UART_RX_BUFFER) {
        uartRxBuffer->readed = 1;
        uartRxBuffer->offset = 0;
        uartRxBuffer->filled = 0;

        gotoNextBufferToRead();
    }

    return itemsProcessed;
}

void CanHacker_ErrorCallback(CanHacker_HandleTypeDef *canhacker, char *message) {
    throwError(message);
}

void CanHacker_CanTxMsgReadyCallback(CanHacker_HandleTypeDef *canhacker, CanTxMsgTypeDef *txMsg) {
    CanTxMsgTypeDef *txMsgQ = malloc(sizeof(CanTxMsgTypeDef));
    memcpy(txMsgQ, txMsg, sizeof(CanTxMsgTypeDef));

    osMessagePut (canTxQueueHandle, (uint32_t)txMsgQ, osWaitForever);
    txCan();

    return;
}

void CanHacker_UartMsgReadyCallback(CanHacker_HandleTypeDef *canhacker, uint8_t *line) {
    int len = strlen((char *)line);
    char *str = malloc(len+1);
    memcpy(str, line, len+1);
    osMessagePut (uartTxQueueHandle, (uint32_t)str, osWaitForever);
    txUart();
}

uint32_t CanHacker_GetTimestampCallback(CanHacker_HandleTypeDef *canhacker) {
    return htim6.Instance->CNT;
}

void CanHacker_StartTimerCallback(CanHacker_HandleTypeDef *canhacker) {
    HAL_TIM_Base_Start(&htim6);
}

void CanHacker_StopTimerCallback(CanHacker_HandleTypeDef *canhacker) {
    HAL_TIM_Base_Stop(&htim6);
}

/* USER CODE END 4 */

/* StartDefaultTask function */
void StartDefaultTask(void const * argument)
{
  /* init code for USB_DEVICE */
  //MX_USB_DEVICE_Init();

  /* USER CODE BEGIN 5 */
    rxCan();

    /* Infinite loop */
    for(;;)
    {
        int itemsProcessed = 0;

        osEvent canEvent = osMessageGet(canRxQueueHandle, osWaitForever);
        if (canEvent.status == osEventMessage) {

            CanHacker_Receive_CanMsg(&hcanhacker, (CanRxMsgTypeDef *)canEvent.value.p);
            free(canEvent.value.p);

            itemsProcessed++;
        }

        // sleep only when nothing to do
        if (!itemsProcessed) {
            osDelay(1);
        }
    }
  /* USER CODE END 5 */ 
}

/* StartUartRxDmaTask function */
void StartUartRxDmaTask(void const * argument)
{
  /* USER CODE BEGIN StartUartRxDmaTask */

    currentUartRxBuffer = 0;
    currentUartRxBufferToRead = 0;
    startUartDmaReceive(&huart1, &uartRxBuffer[currentUartRxBuffer]);

    for(;;) {
        int itemsProcessed = processUartDmaBuffer(&huart1, &uartRxBuffer[currentUartRxBufferToRead]);
        if (!itemsProcessed) {
            osDelay(1);
        }
    }
  /* USER CODE END StartUartRxDmaTask */
}

#ifdef USE_FULL_ASSERT

/**
   * @brief Reports the name of the source file and the source line number
   * where the assert_param error has occurred.
   * @param file: pointer to the source file name
   * @param line: assert_param error line source number
   * @retval None
   */
void assert_failed(uint8_t* file, uint32_t line)
{
  /* USER CODE BEGIN 6 */
  /* User can add his own implementation to report the file name and line number,
    ex: printf("Wrong parameters value: file %s on line %d\r\n", file, line) */
    printf("Wrong parameters value: file %s on line %d\r\n", (char *)file, (int *)line);
  /* USER CODE END 6 */

}

#endif

/**
  * @}
  */ 

/**
  * @}
*/ 

/************************ (C) COPYRIGHT STMicroelectronics *****END OF FILE****/

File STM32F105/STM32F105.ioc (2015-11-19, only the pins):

Mcu.UserName=STM32F105RBTx
PA10.Signal=USART1_RX
PA11.Signal=USB_OTG_FS_DM
PA12.Signal=USB_OTG_FS_DP
PA13.Signal=SYS_JTMS-SWDIO
PA14.Signal=SYS_JTCK-SWCLK
PA9.Signal=USART1_TX
PB5.GPIO_Label=TJA_EN
PB5.Signal=GPIO_Output
PB6.GPIO_Label=TJA_STB
PB6.Signal=GPIO_Output
PB7.GPIO_Label=TJA_ERR
PB7.Signal=GPIO_Input
PB8.Signal=CAN1_RX
PB9.Signal=CAN1_TX
PD0-OSC_IN.Signal=RCC_OSC_IN
PD1-OSC_OUT.Signal=RCC_OSC_OUT

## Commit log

2015-09-22 First Sheme
    [STM32_CAN-USB.brd, STM32_CAN-USB.sch]
2015-11-04 SWD pin labels
    [STM32_CAN-USB.brd]
2015-11-05 change scheme, unrouted board
    [STM32_CAN-USB.brd, STM32_CAN-USB.sch]
2015-11-05 TJA networks names
    [STM32_CAN-USB.brd, STM32_CAN-USB.sch]
2015-11-05 Move eagle files to subfolder
    [STM32_CAN-USB.brd, STM32_CAN-USB.sch]
2015-11-05 Add eclipse project
    [STM32F105.cfg]
2015-11-05 USART TX DMA
2015-11-08 UART RX via DMA
2015-11-11 Revert sch & brd
    [STM32_CAN-USB.brd, STM32_CAN-USB.sch]
2015-11-11 CAN pin labels
    [STM32_CAN-USB.brd]
2015-11-11 TJA1055 library prototype
2015-11-12 Labels, pin headers optimization
    [STM32_CAN-USB.brd, STM32_CAN-USB.sch]
2015-11-16 added pull-down resistors on the lines EN and STB
    [STM32_CAN-USB.brd, STM32_CAN-USB.sch]
